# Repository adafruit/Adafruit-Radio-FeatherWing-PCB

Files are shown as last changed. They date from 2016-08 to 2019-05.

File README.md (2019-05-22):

## Adafruit Radio FeatherWings PCB
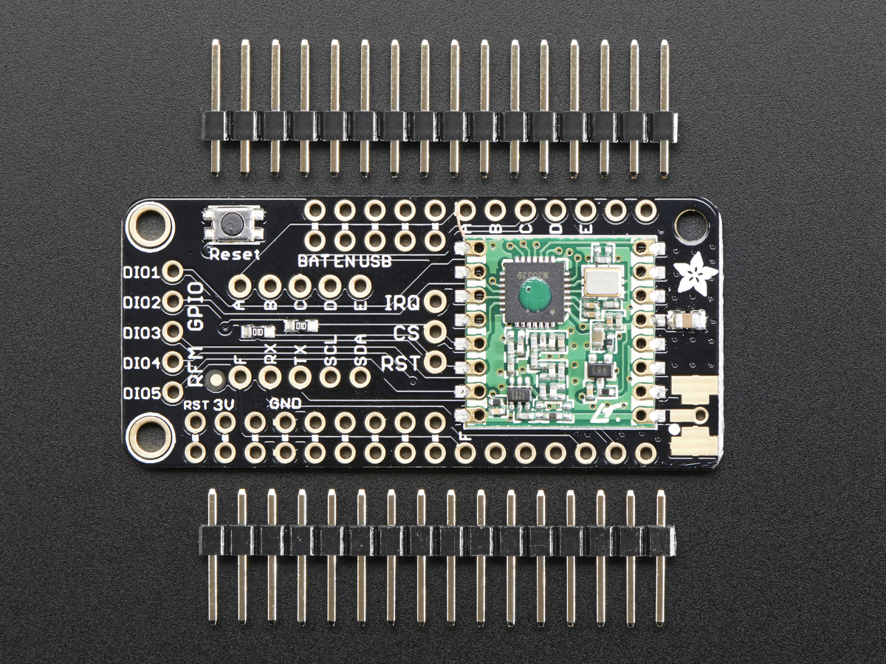
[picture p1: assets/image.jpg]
<a href="http://www.adafruit.com/products/3229"><br/>
Click here to purchase one from the Adafruit shop</a>

Add short-hop wireless to your Feather with these RadioFruit Featherwings. These add-ons for any Feather board will let you integrate packetized radio (with the RFM69 radio) or LoRa radio (with the RFM9x's). These radios are good options for kilometer-range radio, and paired with one of our WiFi, cellular or Bluetooth Feathers, will let you bridge from 433/900 MHz to the Internet or your mobile device.

These radio modules come in four variants (two modulation types and two frequencies) The RFM69's are easiest to work with, and are well known and understood. The LoRa radios are exciting, longer-range and more powerful but also more expensive.

- [RFM69 @ 433 MHz](https://www.adafruit.com/products/3230) - basic packetized FSK/GFSK/MSK/GMSK/OOK radio at 433 MHz for use in Europe ITU 1 license-free ISM, or for amateur use with restrictions (check your local  amateur regulations!)
- [RFM69 @ 900 MHz](https://www.adafruit.com/products/3229) - basic packetized FSK/GFSK/MSK/GMSK/OOK radio at 868 or 915 MHz for use in Americas ITU 2 license-free ISM, or for amateur use with restrictions (check your amateur regulations!)
- [RFM98 @ 433 MHz](https://www.adafruit.com/products/3232) - LoRa capable radio at 433 MHz for use in Europe ITU 1 license-free ISM, or for amateur use with restrictions (check your local amateur regulations!)
- [RFM95 @ 900 MHz](https://www.adafruit.com/products/3231) - LoRa capable radio at 868 or 915 MHz for use in Americas ITU 2 license-free ISM, or for amateur use with restrictions (check your local amateur regulations!)

For more details, check out the product pages at

   * https://www.adafruit.com/products/3229
   * https://www.adafruit.com/products/3230
   * https://www.adafruit.com/products/3231
   * https://www.adafruit.com/products/3232
   
PCB files for the Adafruit Radio FeatherWing (RFM69 / RFM9x). The format is EagleCAD schematic and board layout

### License

Adafruit invests time and resources providing this open source design, please support Adafruit and open-source hardware by purchasing products from [Adafruit](https://www.adafruit.com)!

All text above must be included in any redistribution

Designed by Limor Fried/Ladyada for Adafruit Industries.
Creative Commons Attribution/Share-Alike, all text above must be included in any redistribution. 
See license.txt for additional information.

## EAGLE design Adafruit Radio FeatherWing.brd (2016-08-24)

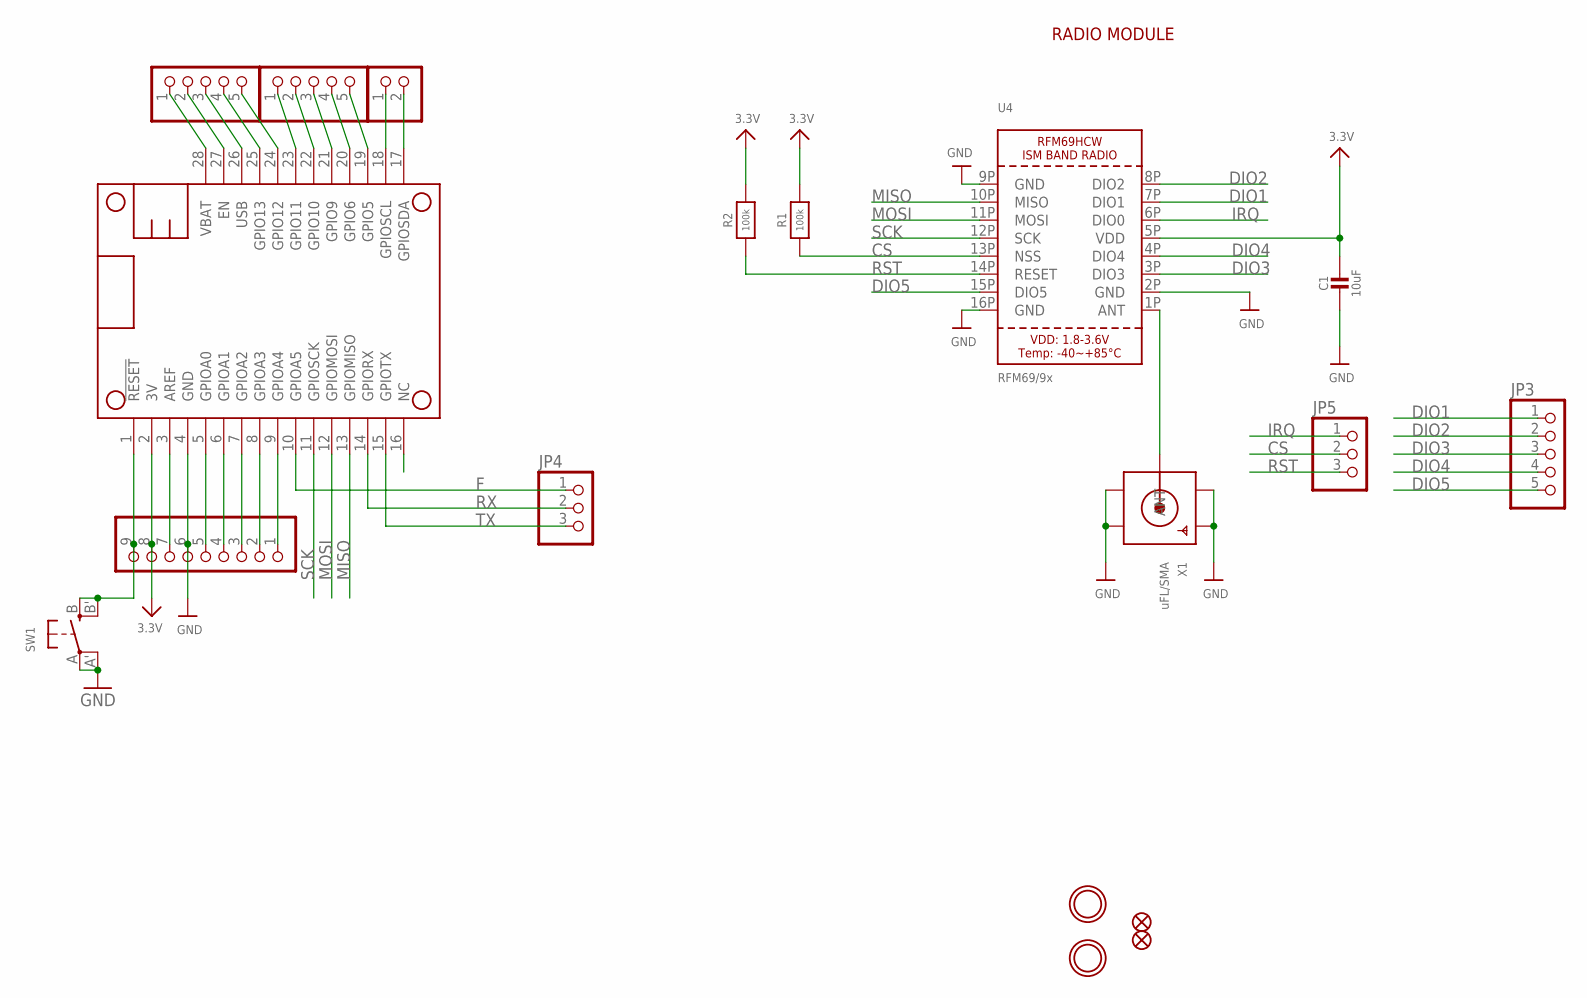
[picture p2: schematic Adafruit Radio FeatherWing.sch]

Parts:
C1: 10uF; 0805-NO
FID1, FID2: FIDUCIAL""; FIDUCIAL_1MM
JP1: HEADER-1X970MIL; 1X09_ROUND_70
JP2, JP3: HEADER-1X570MIL; 1X05_ROUND_70
JP4, JP5: HEADER-1X376MIL; 1X03_ROUND_76
JP6: HEADER-1X2ROUND; 1X02_ROUND
JP7: HEADER-1X576MIL; 1X05_ROUND_76
MS1: FEATHERWING_NOHOLES
R1, R2: 100k; 0603-NO
SW1: SWITCH_TACT_SMT4.6X2.8; BTN_KMR2_4.6X2.8
U4: RFM69/9x; RFMHCW_SMT
U$7, U$8: MOUNTINGHOLE2.5; MOUNTINGHOLE_2.5_PLATED
X1: uFL/SMA; SMA_EDGELAUNCH_UFL

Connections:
3.3V: C1.1, JP1.8, MS1.2 (3V), R1.2, R2.2, U4.5P (VDD)
A: JP7.1, MS1.23 (GPIO11)
ANT: U4.1P (ANT), X1.P (ANT)
B: JP7.2, MS1.22 (GPIO10)
C: JP7.3, MS1.21 (GPIO9)
CS: JP5.2, R1.1, U4.13P (NSS)
D: JP7.4, MS1.20 (GPIO6)
DIO1: JP3.1, U4.7P (DIO1)
DIO2: JP3.2, U4.8P (DIO2)
DIO3: JP3.3, U4.3P (DIO3)
DIO4: JP3.4, U4.4P (DIO4)
DIO5: JP3.5, U4.15P (DIO5)
E: JP7.5, MS1.19 (GPIO5)
EN: JP2.2, MS1.27 (EN)
F: JP4.1, MS1.10 (GPIOA5)
G: JP2.5, MS1.24 (GPIO12)
GND: C1.2, JP1.6, MS1.4 (GND), SW1.A, SW1.A' (P1), U4.2P (GND), U4.9P (GND), U4.16P (GND), X1.GND@1 (GND1), X1.GND@2 (GND2), X1.GND@3 (GND3), X1.GND@4 (GND4)
H: JP2.4, MS1.25 (GPIO13)
I: JP1.5, MS1.5 (GPIOA0)
IRQ: JP5.1, U4.6P (DIO0)
J: JP1.4, MS1.6 (GPIOA1)
K: JP1.3, MS1.7 (GPIOA2)
L: JP1.2, MS1.8 (GPIOA3)
M: JP1.1, MS1.9 (GPIOA4)
MISO: MS1.13 (GPIOMISO), U4.10P (MISO)
MOSI: MS1.12 (GPIOMOSI), U4.11P (MOSI)
unnamed: JP1.7, MS1.3 (AREF)
unnamed: JP1.9, MS1.1 (!RESET), SW1.B (S), SW1.B' (S1)
NC: MS1.16 (NC)
RST: JP5.3, R2.1, U4.14P (RESET)
RX: JP4.2, MS1.14 (GPIORX)
SCK: MS1.11 (GPIOSCK), U4.12P (SCK)
SCL: JP6.1, MS1.18 (GPIOSCL)
SDA: JP6.2, MS1.17 (GPIOSDA)
TX: JP4.3, MS1.15 (GPIOTX)
USB: JP2.3, MS1.26 (USB)
VBAT: JP2.1, MS1.28 (VBAT)

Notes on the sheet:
RADIO MODULE

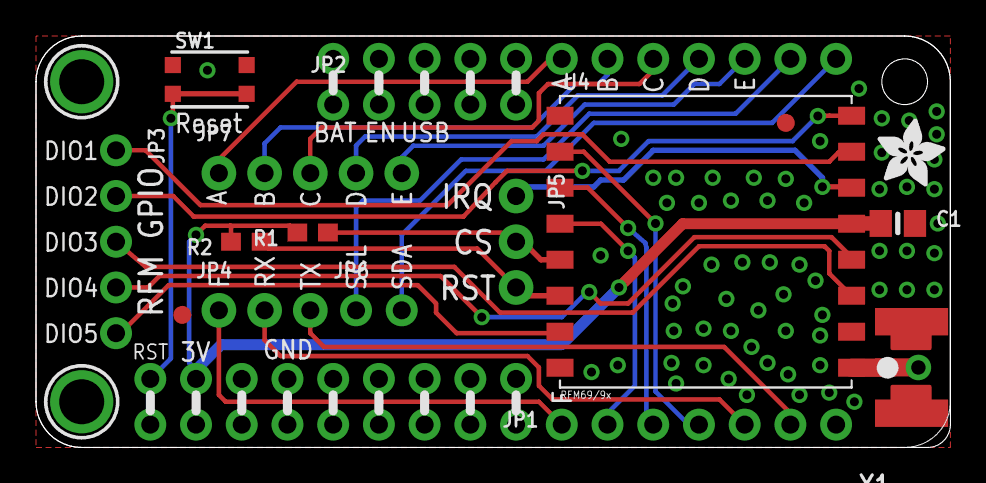
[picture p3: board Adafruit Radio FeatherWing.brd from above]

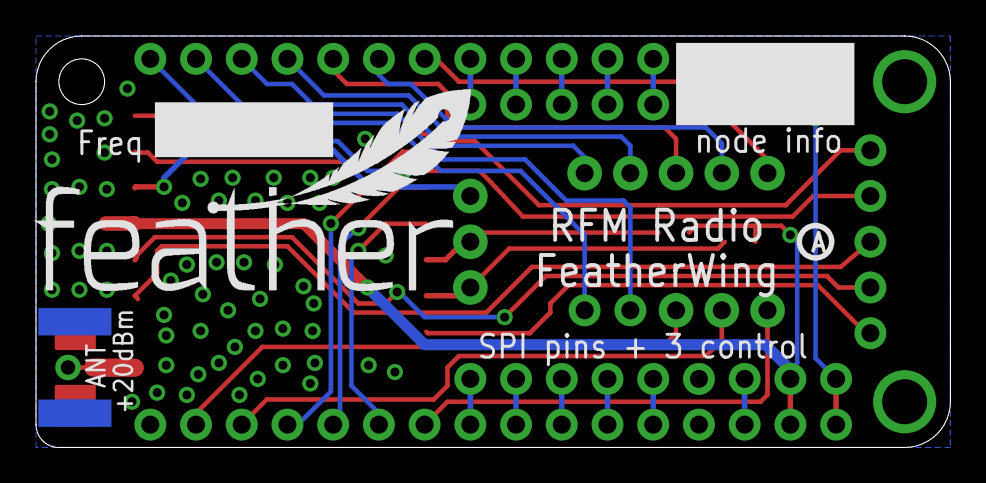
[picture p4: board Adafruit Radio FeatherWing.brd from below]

Board: 2 copper layers, 50.8 x 22.9 mm, 21 parts (2 on the bottom side), 36 nets.

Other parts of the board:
U$14: PCBFEAT-REV-040
U$15: ADAFRUIT_3.5MM
U$16: FEATHERLOGO

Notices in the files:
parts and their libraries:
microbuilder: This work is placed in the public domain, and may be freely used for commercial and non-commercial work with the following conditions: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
